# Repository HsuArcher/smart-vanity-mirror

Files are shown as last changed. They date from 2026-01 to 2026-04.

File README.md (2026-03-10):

# smart-vanity-mirror

Custom built ESP8266 based smart vanity mirror with touch controls, USB-C power and programming integration, custom CADed frame and custom PCB.

## Features

- Adustable LEDs brightness and color
- Touch Sensor Controls
- Custom Built Housing
- USB C Port for Power and Programming

## Hardware Overview

What this shows:
USB-C Programmer and Power Supply, Voltage Regulation, ESP8266 Microcontroller, Touch Input Circuit, LED Output Stage

Electrical Schematic

### USB-C and USB to Serial Port

The system is powered and programmed through a USB-C connector supplying 5 V and a CH340C USB to Serial UART converter.

Key design elements:
- VBUS provides 5 V input.
- CC resistors are used to negotiate default USB power mode.
- The CH340C communicates with the ESP8266 when the USB C is connected to a computer. 
- GPIO 0 boot mode circuitry and Reset circuitry
- A polyfuse is used as overcurrent protection.

### Voltage Regulation

The ESP8266 operates at 3.3 V, so a voltage regulator steps down 5 V from USB-C to 3.3 V.

Key design elements:
- 5V to 3.3V Buck Converter

### ESP8266 Microcontroller

The ESP8266 serves as the main controller for, handling touch input, driving LED outputs, and managing firmware logic

Key design elements:
- Proper decoupling capacitors near VCC
- EN (enable) pull-up resistor
- Manual Reset Switch

### Touch Input Circuit

The FDC1004-Q1 is a 4-Channel Capacitance-to-Digital Converter which is used to detect when the user touches metal pads. This data is sent to the ESP8266 to control the lights

<!-- Future Improvements

Facial recognition lighting presets

Mobile app control

Ambient light auto-adjustment

Bluetooth speaker integration -->

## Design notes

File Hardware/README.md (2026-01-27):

# Hardware
PCB design, schematics, and CAD files for the smart vanity mirror.

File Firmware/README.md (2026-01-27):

# Firmware
ESP8266 firmware for LED control, capcitive touch sensors, and system logic

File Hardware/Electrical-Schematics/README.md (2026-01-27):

# Schematics
KiCAD schematics files and PDFs

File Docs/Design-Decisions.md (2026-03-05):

# Design Decisions
This document records major hardware and system level decisions for the smart vanity mirror.

---

## System Overview

Brief description of the system's main architecture

- ESP8266 Microcontroller
- Capactive touch sensors (MPR121)
- Addressable LED Strip
- USB-C Programmer port and Power input

---

## Power Decisions

### Power Input Selection
**Decision:** USB-C selected as the primary power source

**Reasoning:** 
The initial power source was a dedicated external 5V power supply. This however was too heavy and big to be a reasonable choice for a small desk sized vanity mirror. A USB-C port was already included in the schematic due to it being used to program the ESP8266 and was adapted to become a power input device.

**Notes:** 
- USB-C implemented to be in 5V mode 

---

### Input Protection
**Decision:** A polyfuse was added on the 5V input rail

**Reasoning:** 
For the longevity of the product and the safety of the user a polyfuse was added. The polyfuse provides protection against short circuit events and accidental overload.

**Notes:** 
- Polyfuse hold current is based on the worst case scenario for the current draw from the WS2812B RGB LED Strip and other electronics. 

---

### Voltage Regulator

**Decision:** a buck regulator is used to convert 5V to 3.3V

**Reasoning:** 
The ESP8266, Touch sensors, and the USB Serial converter requires a stable 3.3V supply with a enough current to handle short current peaks. 

---

## Microcontroller Selection

### ESP8266
**Descision:** The ESP8266 is selected as the primary microcontroller.

**Reasoning:**
4 different microcontrollers were taken into consideration for this project. The selection criteria priotizes cost, ease of integration, and the microcontroller ecosystem.

| Criteria | Weight (%) | ESP32  | ESP8266 | ATmega328P | STM32L |
| --- | --- | --- | --- | --- | --- |
| Power Consumption | 10% | 3 | 2 | 5 | 4 |
| Cost | 25% | 3 | 5 | 4 | 4 |
| Ease of Programming | 15% | 5 | 4 | 4 | 2 |
| Long-term Scalability | 10% | 5 | 4 | 2 | 4 |
| PCB Integration | 20% | 4 | 4 | 5 | 2 |
| Microcontroller Ecosystem | 20% | 5 | 5 | 3 | 2 |
| Weighted Total: | 100% | 4.1 | 4.25 | 3.9 | 2.9 |

**Notes:**
- The ESP Microcontroller line was heavily recommended due to its simplicity and its low cost. Furthermore I have some experience with the ESP32 from participating in the ASU Formula SAE team. 
- The ESP8266 was chosen over the ESP32 because of its cheaper price while still meeting the functional and preformance requirments. 

---

## LED Control

### LED Strip

**Decision:** WS2812 (NeoPixel) addressable RGB LEDs

**Reasoning:**
- RGB capabilities that allows for specific colors
- Widely supported libraries and documentation

### Logic Level Shifting

**Decision:** SN74LV1T34QDBVRQ1 single buffer is used for LED data signaling

**Reasoning:**
The ESP8266 outputs 3.3V logic levels, while the NeoPixel LEDs requires a reliable 5V logic-level data signal. The initial logic shifter used was a SN74AHCT125 quad buffer which was chosen because it was readily avaliable for a physical prototype. Only one of the input and output pins out of the 4 possible pins was being used so for the goal of simplicity the SN74LV1T34QDBVRQ1 single buffer was chosen instead. 

---

## Touch Sensors

## Capacitive Touch Controller

**Decision:** FDC1004QDGSRQ1 used for capactive touch sensing

**Reasoning:**
- Supports multiple independent electrodes 
- Proven performance for touch detection through non-conductive materials

**Notes:**
- Due to the limitations of manufactoring the MPR121 could not be used. 
---

## USB Interface

### USB to ESP8266 Communication

**Decision:** CH340C USB serial converter 

**Reasoning:**
- No external crystal required

---

## Mechanical Design

### PCB Design

**Decision:** Custom PCB designed in KiCAD

**Reasoning:**
A custom PCB reduces wiring complexity and allows slim and small profile for the electronics

---

## TODO
- Finalize PCB Layout
- Firmware development and integration for the ESP8266
- Solidworks model for the pcb enclosure and mirror design

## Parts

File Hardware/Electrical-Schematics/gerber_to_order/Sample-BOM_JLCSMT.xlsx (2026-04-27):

Comment | Designator | Footprint | JLCPCB Part #（optional）
100uF | C1 | CAP-SMD_L3.5-W2.8 | C16133
15K | R5,R6 | R0603 | C22809
DC-005-20A_C136744 | DC1 | DC-IN-TH_DC-005-20A | C136744
Header-Female-2.54_1x8 | P2,P3 | HDR-TH_8P-P2.54-V | C27438
K2-1102DP-C4SW-04 | SW1 | KEY-TH_4P-L6.0-W6.0-P4.50-LS6.5 | C110153
ATMEGA328P-PU | U1 | DIP-28_L34.6-W7.3-P2.54-LS10.2-BL | C33901
670688000 | USB1 | USB-B-TH_67068-8000 | C114097

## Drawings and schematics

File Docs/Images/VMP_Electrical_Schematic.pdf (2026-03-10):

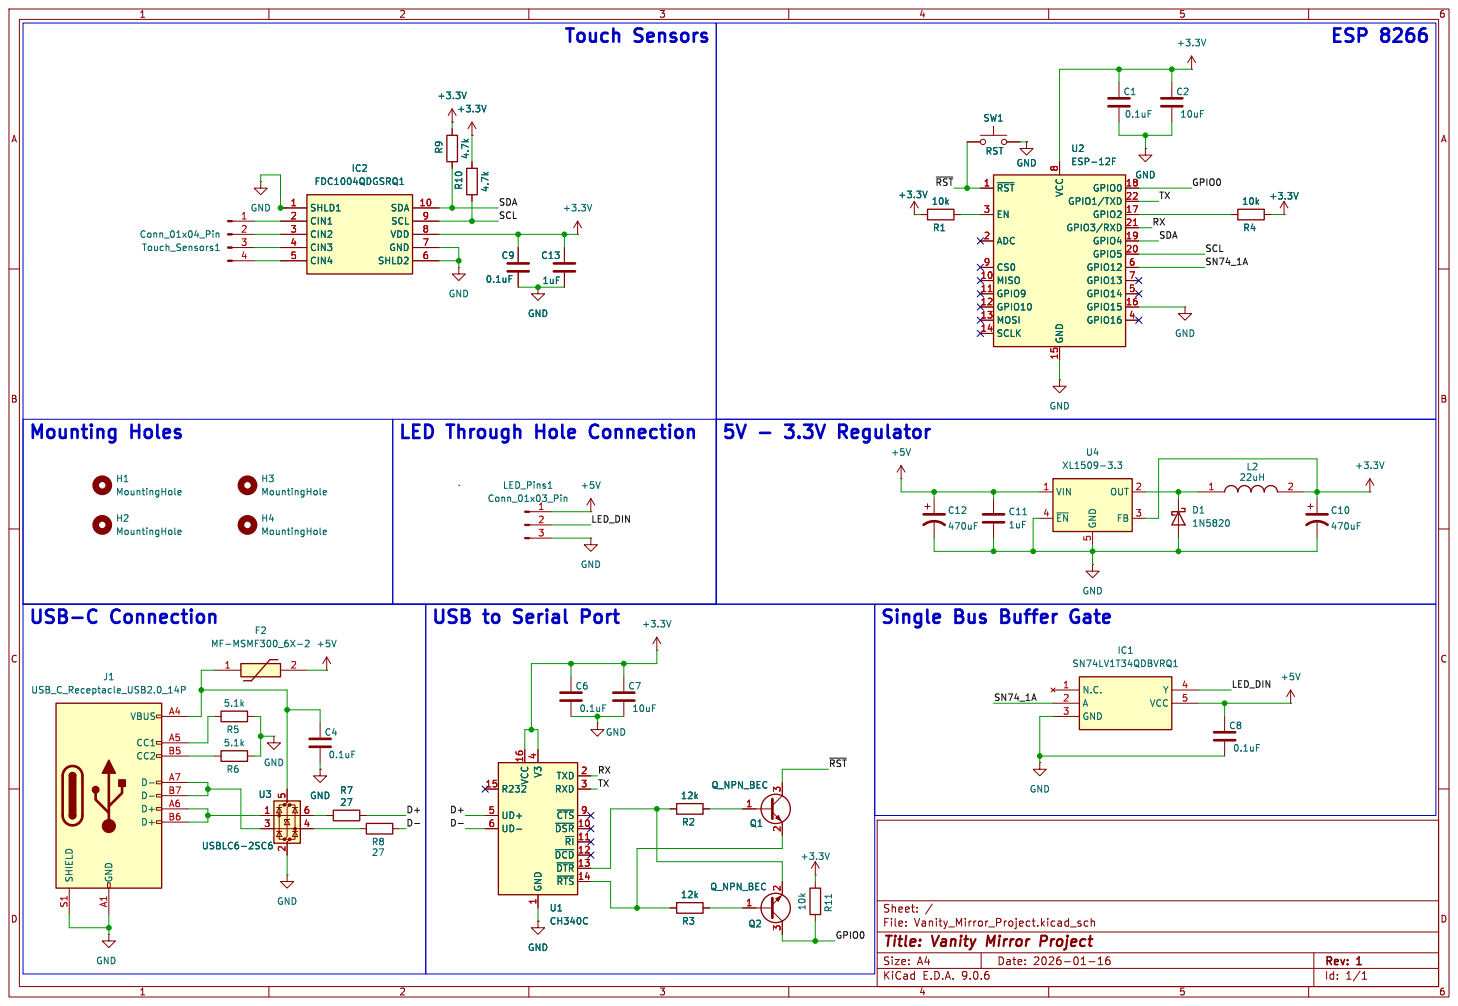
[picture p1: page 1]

1 TXD 2 RXD 3 ~{CTS}9 ~{DSR} 10 ~{RI} 11 ~{DCD} 12 ~{DTR} 13 ~{RTS} 14 U1 CH340C GND

1 TXD 2 RXD 3 ~{CTS}9 ~{DSR} 10 ~{RI} 11 ~{DCD} 12 ~{DTR} 13 ~{RTS} 14 GND

Id: 1/1 Title: Vanity Mirror Project File: Vanity_Mirror_Project.kicad_sch Sheet: /

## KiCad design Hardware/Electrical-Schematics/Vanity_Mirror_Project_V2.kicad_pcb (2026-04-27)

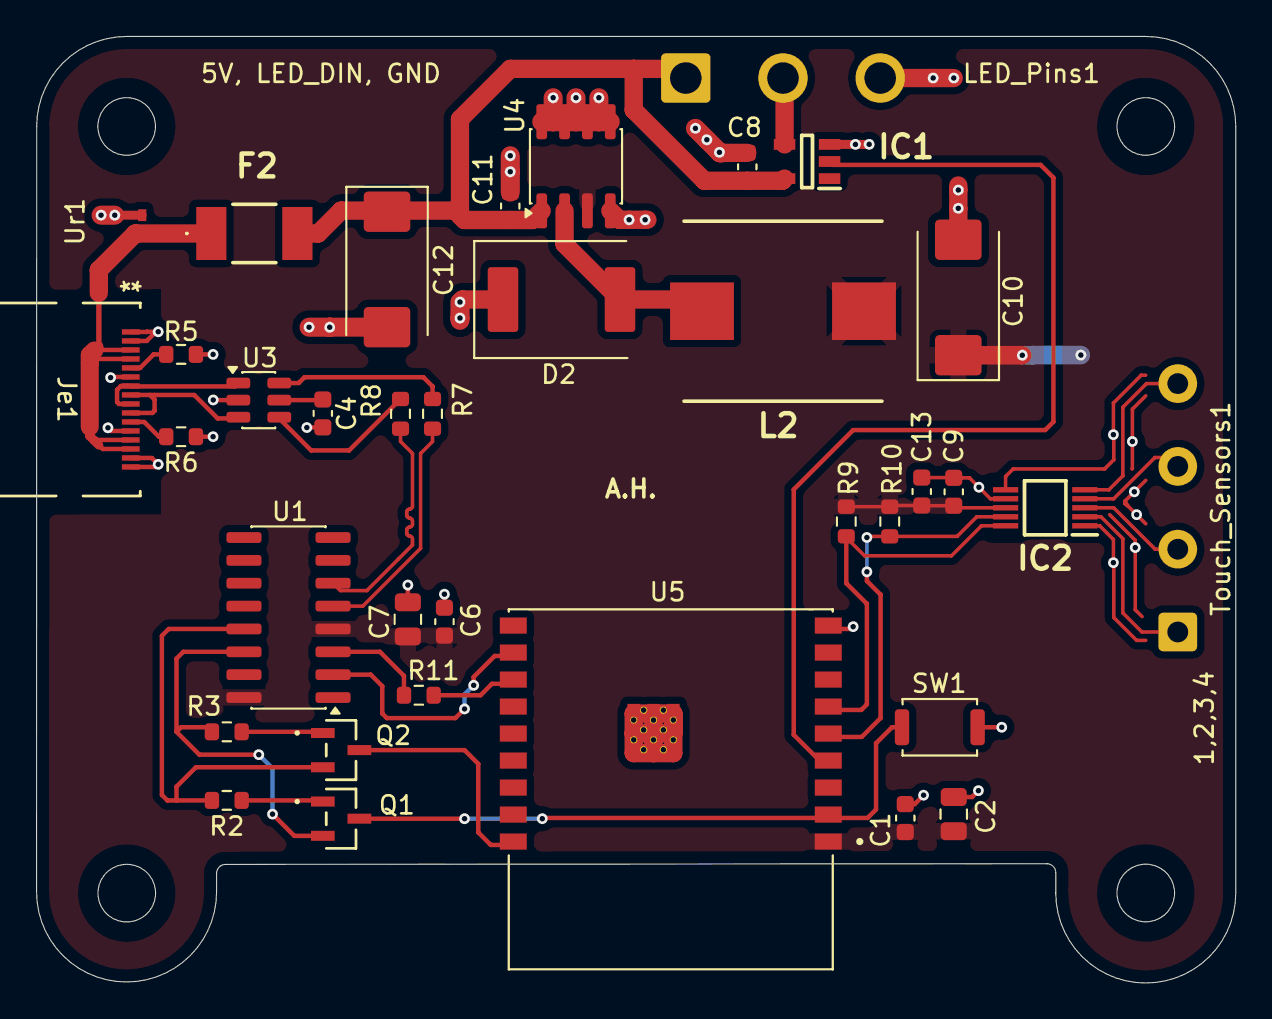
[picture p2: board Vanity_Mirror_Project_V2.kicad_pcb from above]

Board: 2 copper layers, 66.6 x 52.6 mm, 40 parts (0 on the bottom side), 30 nets.

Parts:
C1, C4, C6, C8, C9: 0.1uF; C_0603_1608Metric
C2, C7: 10uF; C_0805_2012Metric
C10: 330uF; CP_EIA-7343-31_Kemet-D_HandSolder
C11, C13: 1uF; C_0603_1608Metric
C12: 470uF; CP_EIA-7343-31_Kemet-D_HandSolder
D2: Diode; P27_DO-214AB_SMC
F2: MF-MSMF300_6X-2; MFMSMF3006X2
H1, H2, H3, H4: MountingHole; MountingHole_3.2mm_M3
IC1: SN74LV1T34QDBVRQ1; SOT95P280X145-5N
IC2: FDC1004QDGSRQ1; SOP50P490X110-10N
Je1: 10155435-00011LF-Custom; 2130830005_MOL
L2: 22uH; INDPM110100X400N
LED_Pins1: Conn_01x03_Pin; SolderWire-1sqmm_1x03_P5.4mm_D1.4mm_OD2.7mm
Q1, Q2: Q_NPN_BEC; SOT-23-3_1P4X3P040_ONS
R2, R3: 12k; R_0603_1608Metric
R5, R6: 5.1k; R_0603_1608Metric
R7, R8: 27; R_0603_1608Metric
R9, R10: 4.7k; R_0603_1608Metric
R11: 499; R_0603_1608Metric
SW1: RST; SW_Push_SPST_NO_Alps_SKRK
Touch_Sensors1: Conn_01x04_Pin; SolderWire-0.5sqmm_1x04_P4.6mm_D0.9mm_OD2.1mm
U1: CH340C; SOIC-16_3.9x9.9mm_P1.27mm
U3: USBLC6-2SC6; SOT-23-6
U4: XL1509-3.3; SOIC-8_3.9x4.9mm_P1.27mm
U5: ESP32-C3-WROOM-02-N4; MODULE_ESP32-C3-WROOM-02-H4
Ur1: CPDQR5V0U; CPDQR

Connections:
+3.3V: C1.1, C2.1, C6.1, C7.1, C9.1, C10.1, C13.1, IC2.8 (VDD), L2.2, R9.2, R10.2, U1.4 (V3), U1.16 (VCC), U4.3 (FB), U5.1 (3V3)
+5V: C8.1, C11.1, C12.1, F2.2, IC1.5 (VCC), LED_Pins1.1, U4.1 (VIN)
/D+: R7.1, U1.5 (UD+)
/D-: R8.1, U1.6 (UD-)
/EN: Q1.3 (C), SW1.2, U5.2 (EN)
/GPIO0: Q2.3 (C), U5.18 (IO0)
/LED_DIN: IC1.4 (Y), LED_Pins1.2
/RX: U1.2 (TXD), U5.11 (RXD)
/SCL: IC2.9 (SCL), R10.1, U5.5 (IO6)
/SDA: IC2.10 (SDA), R9.1, U5.6 (IO7)
/SN74_1A: IC1.2 (A), U5.4 (IO5)
/TX: R11.2, U1.3 (RXD)
GND: C1.2, C2.2, C4.2, C6.2, C7.2, C8.2, C9.2, C10.2, C11.2, C12.2, C13.2, D2.1 (A), IC1.3 (GND), IC2.1 (SHLD1), IC2.6 (SHLD2), IC2.7 (GND), Je1.A1 (GND), Je1.A8 (SBU1), Je1.A12 (GND), Je1.B1 (GND), Je1.B8 (SBU2), Je1.B12 (GND), LED_Pins1.3, R5.1, R6.1, SW1.1, U1.1 (GND), U3.2 (GND), U4.4 (~EN), U4.5 (GND), U4.6 (GND), U4.7 (GND), U4.8 (GND), U5.9 (GND), U5.19 (GND__1), U5.20 (GND__2), U5.21 (GND__3), U5.22 (GND__4), U5.23 (GND__5), U5.24 (GND__6), U5.25 (GND__7), U5.26 (GND__8), U5.27 (GND__9), U5.28 (GND__10), U5.29 (GND__11), U5.30 (GND__12), U5.31 (GND__13), U5.32 (GND__14), U5.33 (GND__15), U5.34 (GND__16), U5.35 (GND__17), U5.36 (GND__18), U5.37 (GND__19), U5.38 (GND__20), U5.39 (GND__21), Ur1.2
unnamed: D2.2 (C), L2.1, U4.2 (OUT)
unnamed: IC2.2 (CIN1), Touch_Sensors1.1
unnamed: IC2.3 (CIN2), Touch_Sensors1.2
unnamed: IC2.4 (CIN3), Touch_Sensors1.3
unnamed: IC2.5 (CIN4), Touch_Sensors1.4
unnamed: Je1.A5 (CC1), R5.2
unnamed: Je1.B5 (CC2), R6.2
unnamed: Je1.A6 (D+), Je1.B6 (D+), U3.1 (I/O1)
unnamed: Je1.A7 (D-), Je1.B7 (D-), U3.3 (I/O2)
unnamed: Q1.1 (B), R2.1
unnamed: Q1.2 (E), R3.2, U1.14 (~RTS)
unnamed: Q2.1 (B), R3.1
unnamed: Q2.2 (E), R2.2, U1.13 (~DTR)
unnamed: R7.2, U3.6 (I/O1)
unnamed: R8.2, U3.4 (I/O2)
unnamed: C4.1, F2.1, Je1.A4 (VBUS), Je1.A9 (VBUS), Je1.B4 (VBUS), Je1.B9 (VBUS), U3.5 (VBUS), Ur1.1
unnamed: R11.1, U5.12 (TXD)

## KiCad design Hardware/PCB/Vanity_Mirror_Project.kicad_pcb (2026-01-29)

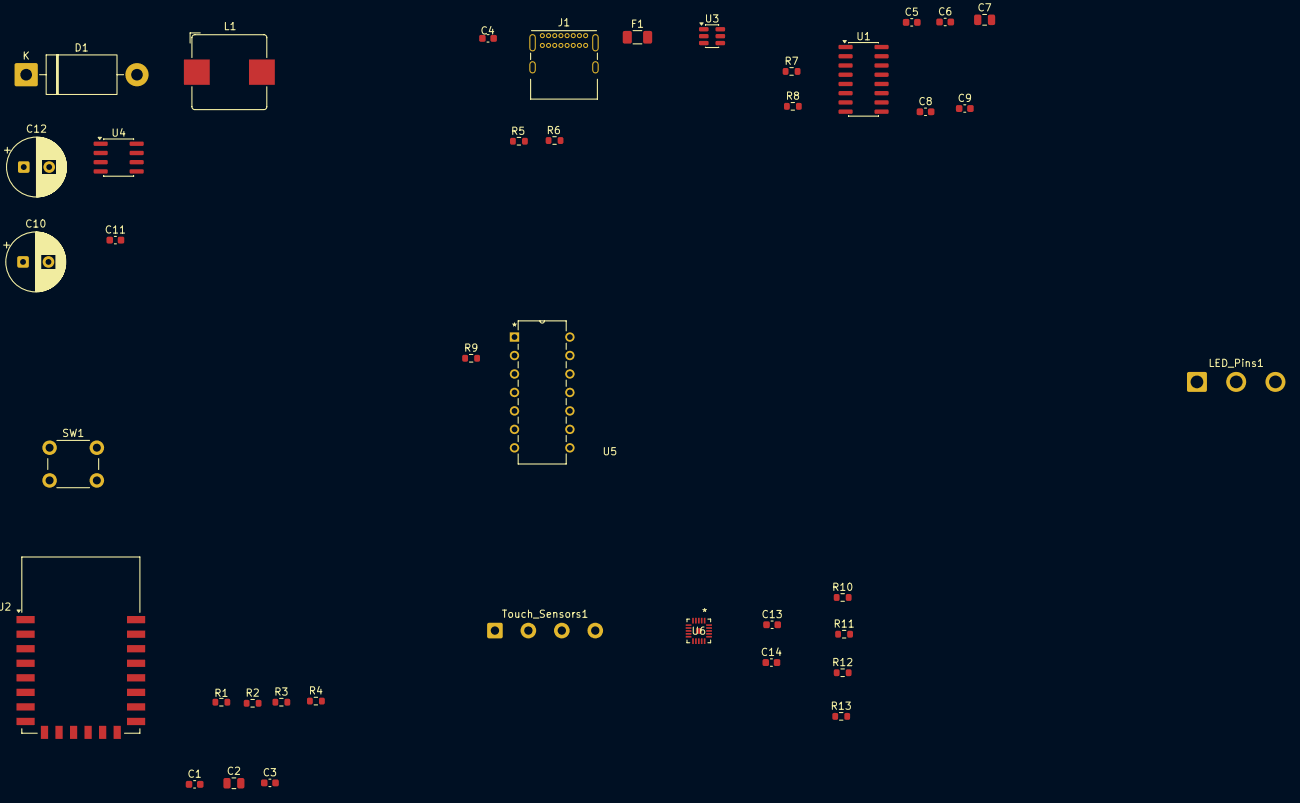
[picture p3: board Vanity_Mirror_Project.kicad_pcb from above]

Board: 2 copper layers, 40 parts (0 on the bottom side), 33 nets, no tracks yet.

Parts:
C1, C3, C4, C5, C6, C8, C9, C13, C14: 0.1uF; C_0603_1608Metric
C2, C7: 10uF; C_0805_2012Metric
C10, C12: 470uF; CP_Radial_D8.0mm_P3.50mm
C11: 1uF; C_0603_1608Metric
D1: 1N5820; D_DO-201AD_P15.24mm_Horizontal
F1: Polyfuse; Fuse_1206_3216Metric
J1: USB_C_Receptacle_USB2.0_14P; USB_C_Receptacle_GCT_USB4085
L1: 22uH; L_Bourns_SRP1038C_10.0x10.0mm
LED_Pins1: Conn_01x03_Pin; SolderWire-1sqmm_1x03_P5.4mm_D1.4mm_OD2.7mm
R1, R2, R3, R4, R11, R12, R13: 10k; R_0603_1608Metric
R5, R6: 5.1k; R_0603_1608Metric
R7, R8: 27; R_0603_1608Metric
R9: 330; R_0603_1608Metric
R10: 75k; R_0603_1608Metric
SW1: RST; SW_PUSH_6mm
Touch_Sensors1: Conn_01x04_Pin; SolderWire-0.5sqmm_1x04_P4.6mm_D0.9mm_OD2.1mm
U1: CH340C; SOIC-16_3.9x9.9mm_P1.27mm
U2: ESP-12F; ESP-12E
U3: USBLC6-2SC6; SOT-23-6
U4: XL1509-3.3; SOIC-8_3.9x4.9mm_P1.27mm
U5: SN74AHCT125N
U6: MPR121QR2; QFN20_FRE

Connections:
+3.3V: C1.1, C2.1, C6.1, C7.1, C10.1, C13.1, L1.2, R1.2, R2.2, R3.2, R4.1, R11.2, R12.2, R13.2, U1.16 (VCC), U2.8 (VCC), U4.3 (FB), U6.20 (VDD)
+5V: C4.1, C11.1, C12.1, F1.1, F1.2, J1.A4 (VBUS), J1.A9 (VBUS), J1.B4 (VBUS), J1.B9 (VBUS), LED_Pins1.1, U3.5 (VBUS), U4.1 (VIN), U5.14 (VCC)
/LED_DIN: LED_Pins1.2, U5.3 (1Y)
/RX: U1.2 (TXD), U2.21 (GPIO3/RXD)
/SCL: R11.1, U2.20 (GPIO5), U6.2 (SCL)
/SDA: R12.1, U2.6 (GPIO12), U6.3 (SDA)
/SN74_1A: R9.2, U2.19 (GPIO4)
/TX: U1.3 (RXD), U2.22 (GPIO1/TXD)
/~DTR: C8.2, R2.1, U2.3 (EN)
/~IRQ: R13.1, U2.7 (GPIO13), U6.1 (*IRQ)
/~RTS: C9.2, R3.1, U2.18 (GPIO0)
GND: C1.2, C2.2, C3.2, C4.2, C5.2, C6.2, C7.2, C10.2, C11.2, C12.2, C13.2, C14.2, D1.2 (A), J1.A1 (GND), J1.A12 (GND), J1.B1 (GND), J1.B12 (GND), J1.S1 (SHIELD), LED_Pins1.3, R5.1, R6.1, R10.1, SW1.1, U1.1 (GND), U2.15 (GND), U2.16 (GPIO15), U3.2 (GND), U4.4 (~EN), U4.5 (GND), U4.6 (GND), U4.7 (GND), U4.8 (GND), U5.1 (*1OE), U5.7 (GND), U6.4 (ADDR), U6.6 (VSS)
unnamed: D1.1 (K), L1.1, U4.2 (OUT)
unnamed: J1.A5 (CC1), R5.2
unnamed: J1.B5 (CC2), R6.2
unnamed: J1.A6 (D+), J1.B6 (D+), U3.1 (I/O1)
unnamed: J1.A7 (D-), J1.B7 (D-), U3.3 (I/O2)
unnamed: R7.2, U3.6 (I/O1)
unnamed: R8.2, U3.4 (I/O2)
unnamed: Touch_Sensors1.1, U6.8 (ELE0)
unnamed: Touch_Sensors1.2, U6.9 (ELE1)
unnamed: Touch_Sensors1.3, U6.10 (ELE2)
unnamed: Touch_Sensors1.4, U6.11 (ELE3)
unnamed: R7.1, U1.5 (UD+)
unnamed: R8.1, U1.6 (UD-)
unnamed: C5.1, U1.4 (V3)
unnamed: C8.1, U1.13 (~DTR)
unnamed: C9.1, U1.14 (~RTS)
unnamed: R4.2, U2.17 (GPIO2)
unnamed: C3.1, R1.1, SW1.2, U2.1 (~RST)
unnamed: R9.1, U5.2 (1A)
unnamed: R10.2, U6.7 (REXT)
unnamed: C14.1, U6.5 (VREG)

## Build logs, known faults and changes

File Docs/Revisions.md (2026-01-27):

# Revisions

## Initial Design
- ESP8266 Microcontroller
- Capacitive touch sensors (MPR121)
- Neopixel LED Strip
- USB-C Connector for Microcontroller programming and power input

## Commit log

2026-01-27 Create Schematics README.md
2026-01-27 Create PCB README.md
2026-01-29 Initial status of the mirror
    committing all the designs, design decisions, and schematics of the project so far
    [Vanity_Mirror_Project.kicad_pcb, Vanity_Mirror_Project.kicad_sch]
2026-02-09 PCB Design Progress
    Made progress with the PCB design and reorganized the gitignores so that it works.
    [Vanity_Mirror_Project.kicad_pcb, Vanity_Mirror_Project.kicad_sch]
2026-03-05 Initial PCB layout and Schematic Revisions
    Revised some wiring in the schematic and fixed some wiring mistakes. Created an initial layout for the PCB
    [Vanity_Mirror_Project.kicad_pcb, Vanity_Mirror_Project.kicad_sch]
2026-03-10 1st PCB design
    Finished the routing of the PCB and added BJTs for auto programming and auto resetting.
    [Vanity_Mirror_Project.kicad_pcb, Vanity_Mirror_Project.kicad_sch]
2026-03-24 updating the version
    changing laptops so pushing the minor changes made so that the new laptop has the most recent version
    [Vanity_Mirror_Project.kicad_pcb]
2026-04-07 Cleaning files
    Switching Kicad versions and switching laptops
    [Vanity_Mirror_Project.kicad_pcb, Vanity_Mirror_Project_V2.kicad_pcb, Vanity_Mirror_Project_V2.kicad_sch]
2026-04-27 2nd version of the design
    Changed multiple footprints to smd parts, Made a 2nd version for the PCB utilizing a power plane. PCB is ready to be manufactured
    [Sample-BOM_JLCSMT.xlsx, Vanity_Mirror_Project.kicad_sch, Vanity_Mirror_Project_V2.kicad_pcb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]
